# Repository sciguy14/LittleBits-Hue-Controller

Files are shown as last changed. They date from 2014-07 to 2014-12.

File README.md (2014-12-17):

LittleBits Hue Controller
=========================
The LittleBits Hue Controller is an easy-to-setup, wall-mountable, physical controller for your Philips Hue lightbulbs. The controller makes it easy to turn the lights on/off, change their brightness, and cycle through preset colors. This is a great project for people who hate having to pull their phone out every time they want to adjust their lights.

Getting Setup
=============
What you'll need
----------------
* Some LittleBits!
    * [Arduino Module](http://www.shareasale.com/r.cfm?B=612266&U=966033&M=53280&urllink=)
	* [Micro USB Power Bit](http://shrsl.com/?~7bfw)
	* [3-way Splitter Bit](http://shrsl.com/?~7bfv)
	* [Bar Graph Bit](http://shrsl.com/?~7bfu)
	* [7-seg Display Bit](http://shrsl.com/?~7bft)
	* [Mounting Board](http://shrsl.com/?~7bfs)
	* [2x Button Bits](http://shrsl.com/?~7bfx)
	* [Dimmer Bit](http://shrsl.com/?~7bfy)
* An always-on Linux Machine. This can be a Raspberry Pi or something similar. These instructions assume a debian-based distro, like Ubuntu or Raspbian.
* A Phillips Hue Hub, and one or more Phillips Hue Bulbs
* Two Micro USB Cables (Right Angle is best)
* A 3D printer (optional, for making the enclosure)
* 4 sets of M3x10 Socket Head Bolts and Nuts (for assembling the enclosure)

3D Print the Enclosure and Assemble the LittleBits
-----------------------
Step 1: Place the Bits on the backer board as shown. Print the button/dial covers. Slightly heat the button/dial covers and press them onto the buttons and covers as shown.
Step 1

Step 2: Print the enclosure. Place the front of the enclosure on the panel as shown.
Step 2

Step 3: Press the four M3 nuts into the four slots on the top cover as shown.
Step 3

Step 4: Place the USB wires into the cutt-out on the rear of the panel as shown.
Step 4

Step 5: Screw the bolts into the nuts and apply a velcro backer as shown.
Step 5

Program the Arduino Bit
-------------------------------
* Provide Power to the controller, and connect the Arduino cable to your computer (workstation computer, not the linux server computer)
* Use the provided Arduino Sketch to program the Arduino Bit via the Arduino IDE (select Arduino Leonardo from the device menu)

Install the Python Prerequisites
--------------------------------
* Log into (locally or via SSH) to the network-connected, always-on linux machine that you'll use (Raspberry Pi is good for this)
* Install Python 2.7 if don't already have it installed: `sudo apt-get install python2.7`
* Install Python PIP if you haven't already: `sudo apt-get install python-dev python-pip`
* Install the PHue Library: `sudo pip install phue`
* Install the PySerial Library: `sudo pip install pyserial`
* Install the CronTab Library: ` sudo pip install python-crontab`

Obtain and Setup the Server Script
----------------------------------
* Stay logged into your network linux machine
* Connect your LittleBits Hue Controller to power, and to a USB port on your linux machine
* On your linux machine, navigate to your home directory, and clone this GitHub repo: `git clone https://github.com/sciguy14/LittleBits-Hue-Controller`
* Navigate to the server script directory: `cd LittleBits-Hue-Controller/server`
* Ensure the script is executable: `chmod 755 LittleBits-Hue-Controller.py`
* Execute the script in setup mode and follow the instructions to automatically setup the system: `./LittleBits-Hue-Controller.py -s`. The output will look something like this:
Setup Screenshot
* That's it! The handler script will now automatically run in the background at boot. You can launch it immediately to observe its output as you toggle the controller, by running: `./LittleBits-Hue-Controller.py`. The screenshot shows the behavior as I adjust brightness, color, and state via the control pad. You can also see it automatically recover when the control pad is unplugged and plugged back in:
Usage Screenshot

More Info
=========
* [Project Post on my Blog](http://www.jeremyblum.com/2014/12/17/littlebits-hue-lighting-controller)
* [LittleBits Project Page](http://littlebits.cc/projects/littlebits-hue-lighting-controller)
* [Thingiverse Project Page](http://www.thingiverse.com/thing:596186)
* [YouTube Demo Video](https://www.youtube.com/watch?v=p_GHpPhFpdo)

License
=======
This work is licensed under the [GNU GPL v3](http://www.gnu.org/licenses/gpl.html).
Please share improvements or remixes with the community, and attribute me (Jeremy Blum, <http://www.jeremyblum.com>) when reusing portions of my code.

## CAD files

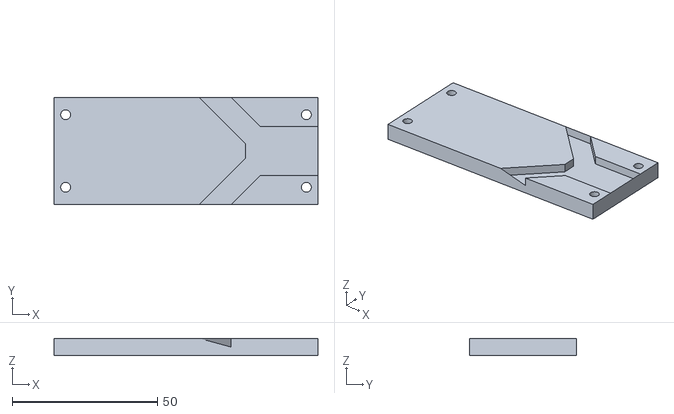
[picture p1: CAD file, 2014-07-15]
mechanical/button_column/bottom bracket/bottom bracket.obj
91.0 x 37.0 x 6.00

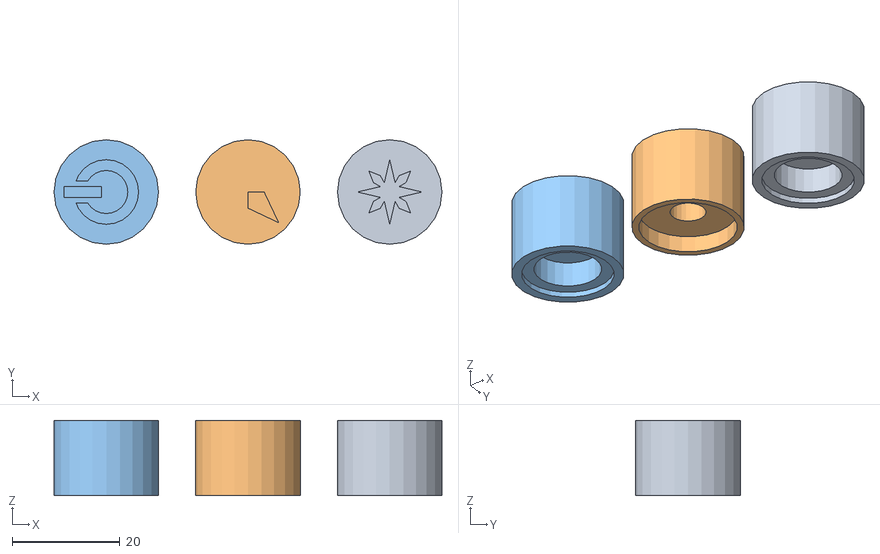
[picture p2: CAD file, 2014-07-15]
mechanical/button_column/button covers/button covers.obj
72.0 x 19.4 x 14.0
Mesh1 Model
Mesh2 Model
Mesh3 Model

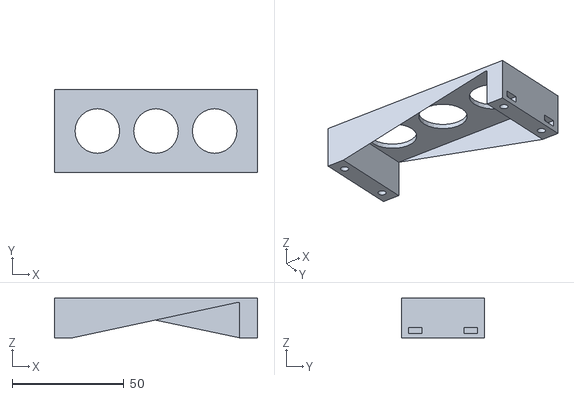
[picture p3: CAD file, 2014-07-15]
mechanical/button_column/top bracket/top bracket.obj
91.0 x 37.0 x 17.8

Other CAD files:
mechanical/button_column/button_column.skp

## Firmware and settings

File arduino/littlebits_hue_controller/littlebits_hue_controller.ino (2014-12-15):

// LittleBits Hue Controller by Jeremy Blum
// Copyright 2014 Jeremy Blum, Blum Idea Labs, LLC.
// http://www.jeremyblum.com
// File: littlebits_hue_controller.ino
// License: GPL v3 (http://www.gnu.org/licenses/gpl.html)

//Interface Pins
const int on_off_button_pin       = 0;  //D0
const int brightness_dial_pin     = A0; //A0
const int mood_button_pin         = A1; //A1
const int brightness_bargraph_pin = 5;  //D5
const int mood_readout            = 9;  //D9

//Constant Values
const int num_moods = 10; //10 mood settings (0-9)

//Button Debouncing & Knob Tracking Variables
boolean on_off_button_last    = LOW;
boolean on_off_button_current = LOW;
boolean mood_button_last      = LOW;
boolean mood_button_current   = LOW;
int     brightness_last;
int     brightness_current;
int     brightness_temp;
int     dial_breaks[4] = {15, 90, 165, 240}; // Values from 0 to 255 where the dial brightness levels occur

//State Variables
int mood = 0;           //Lighting Mood Selection (0-9)
boolean on_off = false; //Light State (on/off, true/false)
boolean transmit = false;

void setup()
{
  //Set Pin Modes
  pinMode(brightness_bargraph_pin, OUTPUT);
  pinMode(mood_readout, OUTPUT);

  //Start Serial communication
  Serial.begin(9600);
  
  //Setup Starting Brightness
  brightness_last = getBrightness(0);
  
  //Setup starting Mood Readout
  setMoodReadout(mood);
}

void loop()
{
  //Allow master to quesy this device and ask if it's the littleBits Controller
  while(Serial.available() > 0)
  {
    if (Serial.read() == '?')
    {
      Serial.println("LittleBits-Hue-Controller");
    }
  }
  
  //On/Off Button Debouncing
  on_off_button_current = debounce(on_off_button_last, on_off_button_pin);
  if (on_off_button_current == HIGH && on_off_button_last == LOW)
  {
    on_off = !on_off;
    transmit = true;
  }
  on_off_button_last = on_off_button_current;
  
  //Mood Button Debouncing
  mood_button_current = debounce(mood_button_last, mood_button_pin);
  if (mood_button_current == HIGH && mood_button_last == LOW)
  {
    mood = mood++;
    if (mood >= num_moods) mood = 0;
    setMoodReadout(mood);
    if (on_off) transmit = true;
  }
  mood_button_last = mood_button_current;
  
  //brightness Selection
  brightness_temp = getBrightness(2);
  if (brightness_temp != 0) brightness_current = brightness_temp;
  if (brightness_current != brightness_last)
  {
    if (on_off) transmit = true;
  }
  brightness_last = brightness_current;
  
  //Transmit knob changes
  if (transmit)
  {    
    if (on_off)
    {
      setBargraph(brightness_current);
      Serial.print("on, ");
      Serial.print(mood);
      Serial.print(", ");
      Serial.println(brightness_current);
    }
    else
    {
      setBargraph(0);
      Serial.println("off");
    }
    transmit = false;  
  }
  
}

//Outputs value from 0-5. 0 means we're in a hysteresis zone, and the brightness should not change.
int getBrightness(int hysteresis)
{
  int brightness_raw = map(analogRead(brightness_dial_pin), 0, 1023, 0, 255);
  int output = 0;
  if                                                    (brightness_raw <= dial_breaks[0]-hysteresis) output = 1;
  else if (brightness_raw > dial_breaks[0]+hysteresis && brightness_raw <= dial_breaks[1]-hysteresis) output = 2;
  else if (brightness_raw > dial_breaks[1]+hysteresis && brightness_raw <= dial_breaks[2]-hysteresis) output = 3;
  else if (brightness_raw > dial_breaks[2]+hysteresis && brightness_raw <= dial_breaks[3]-hysteresis) output = 4;
  else if (brightness_raw > dial_breaks[3]+hysteresis)                                                output = 5;
  return output;
}

void setBargraph(int val)
{
  //Bargraph Bit Limits
  //0>1  1>2  2>3  3>4  4>5 
  //27,  76,  124, 174, 229
  if      (val == 0) analogWrite(brightness_bargraph_pin, 0);
  else if (val == 1) analogWrite(brightness_bargraph_pin, 50);
  else if (val == 2) analogWrite(brightness_bargraph_pin, 100);
  else if (val == 3) analogWrite(brightness_bargraph_pin, 150);
  else if (val == 4) analogWrite(brightness_bargraph_pin, 200);
  else if (val == 5) analogWrite(brightness_bargraph_pin, 250);
}

void setMoodReadout(int mood)
{
  analogWrite(mood_readout, map(mood, 0, 99, 0, 255));
}

boolean debounce(boolean last, int btn_pin)
{
  boolean current = digitalRead(btn_pin);
  if (last != current)
  {
    delay(5);
    current = digitalRead(btn_pin);
  }
  return current;
}

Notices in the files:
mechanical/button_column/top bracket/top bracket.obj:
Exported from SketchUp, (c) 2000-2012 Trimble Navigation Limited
